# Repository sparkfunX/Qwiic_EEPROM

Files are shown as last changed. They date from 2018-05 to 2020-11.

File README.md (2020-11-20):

Qwiic EEPROM - 512Kbit
=======================================

Qwiic EEPROM

[*Qwiic EEPROM - 512Kbit (SPX-14764)*](https://www.sparkfun.com/products/14764)

A simple breakout for the 512kbit common I2C EEPROMs.

Repository Contents
-------------------

* **/Hardware** - Eagle design files (.brd, .sch)
* **/Firmware** - EEPROM test sketch

Documentation
------------

* **[SparkFun External EEPROM Arduino Library](https://github.com/sparkfun/SparkFun_External_EEPROM_Arduino_Library)** - Arduino library for the Qwiic EEPROM - 512Kbit
* **[Datasheet CAT24C512](https://www.onsemi.com/pub/Collateral/CAT24C512-D.PDF)** - Datasheet for EEPROM part number 24512A
* **[Datasheet RM24C512C](https://cdn.sparkfun.com/assets/2/c/4/c/0/DS-RM24C512C_082.pdf)** - Datasheet for EEPROM part number 24512C
* **[Reading and Writing Serial EEPROMs](https://learn.sparkfun.com/tutorials/reading-and-writing-serial-eeproms)** - Tutorial  

License Information
-------------------

This product is _**open source**_! 

Please review the LICENSE.md file for license information. 

If you have any questions or concerns on licensing, please contact technical support on our [SparkFun forums](https://forum.sparkfun.com/viewforum.php?f=152).

Distributed as-is; no warranty is given.

- Your friends at SparkFun.

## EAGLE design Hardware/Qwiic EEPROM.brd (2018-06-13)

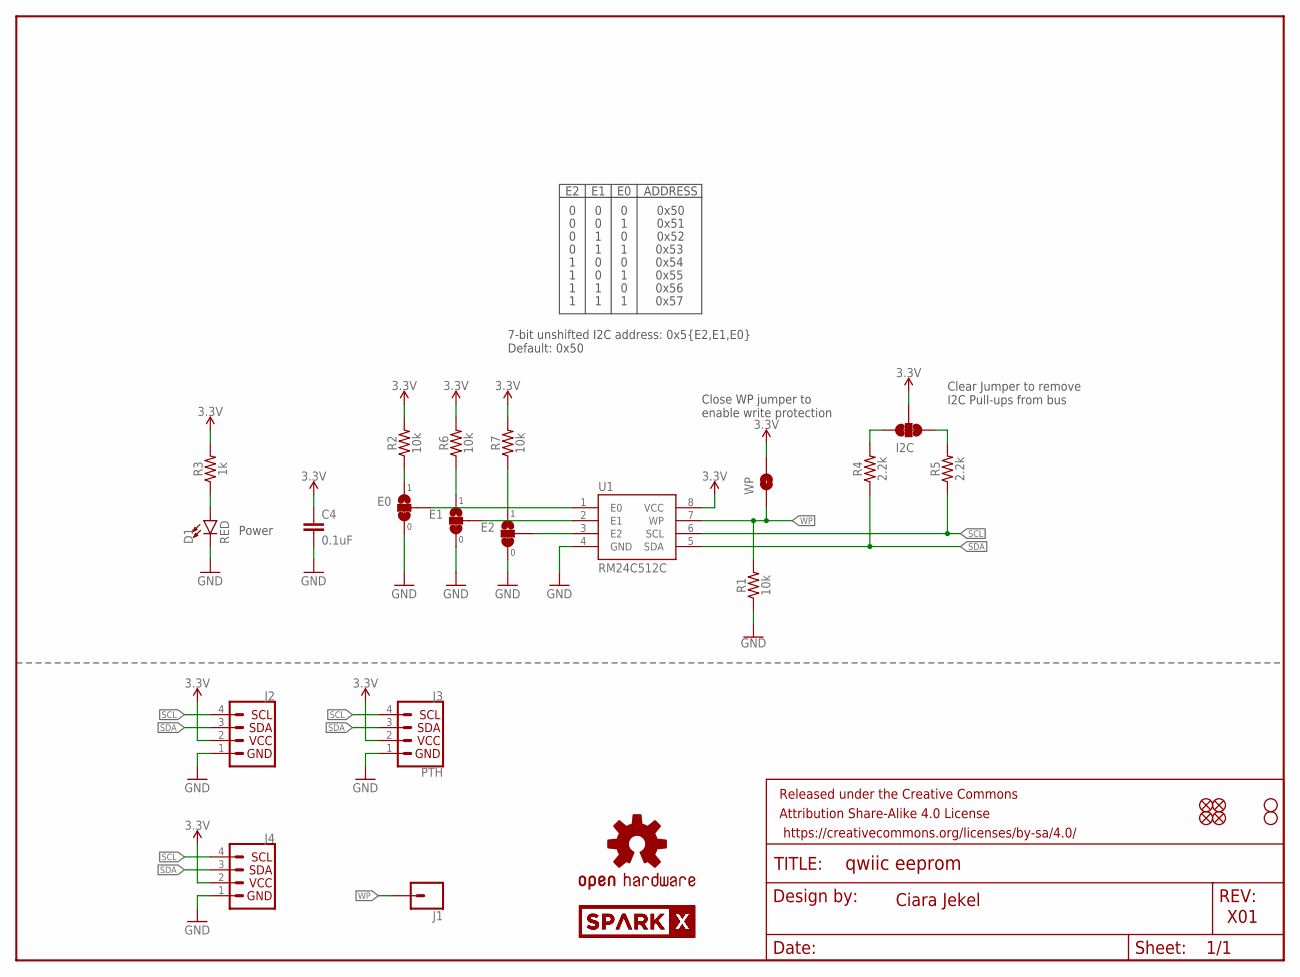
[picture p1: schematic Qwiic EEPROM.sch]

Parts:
C4: 0.1uF; 0603
D1: RED; LED-0603
E0, E1, E2: JUMPER-SMT_3_1-NC_TRACE_SILK; SMT-JUMPER_3_1-NC_TRACE_SILK
FRAME1: FRAME-LETTER; CREATIVE_COMMONS
I2C: JUMPER-SMT_3_2-NC_TRACE_SILK; SMT-JUMPER_3_2-NC_TRACE_SILK
J1: CONN_01PTH_NO_SILK_YES_STOP; 1X01_NO_SILK
J2, J4: QWIIC_CONNECTORJS-1MM; 1X04_1MM_RA
J3: PTH; 1X04_NO_SILK
JP1, JP2, JP5, JP6: FIDUCIALUFIDUCIAL; MICRO-FIDUCIAL
JP3, JP4: STAND-OFF
LOGO1: OSHW-LOGOMINI; OSHW-LOGO-MINI
R1, R2, R6, R7: 10k; 0603
R3: 1k; 0603
R4, R5: 2.2k; 0603
U1: RM24C512C; SO08
U$1, U$2: SPARKX-LOGO4; SPARKX-MEDIUM
WP: JUMPER-SMT_2_NO_SILK; SMT-JUMPER_2_NO_SILK

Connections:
3.3V: C4.1, I2C.2, J2.2, J3.2 (VCC), J4.2, R2.2, R3.2, R6.2, R7.2, U1.8 (VCC), WP.2
GND: C4.2, D1.C, E0.3, E1.3, E2.3, J2.1, J3.1 (GND), J4.1, R1.1, U1.4 (GND)
unnamed: I2C.1, R5.2
unnamed: I2C.3, R4.2
unnamed: D1.A, R3.1
unnamed: E2.2, U1.3 (E2)
unnamed: E1.2, U1.2 (E1)
unnamed: E0.2, U1.1 (E0)
unnamed: E0.1, R2.1
unnamed: E2.1, R7.1
unnamed: E1.1, R6.1
SCL: J2.4, J3.4 (SCL), J4.4, R5.1, U1.6 (SCL)
SDA: J2.3, J3.3 (SDA), J4.3, R4.1, U1.5 (SDA)
WP: J1.1, R1.2, U1.7 (WP), WP.1

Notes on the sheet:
Ciara Jekel
X01
7-bit unshifted I2C address: 0x5{E2,E1,E0} Default: 0x50
Clear Jumper to remove I2C Pull-ups from bus
Power
Close WP jumper to enable write protection
ADDRESS
0x50
0x51
0x52
0x53
0x54
0x55
0x56
0x57

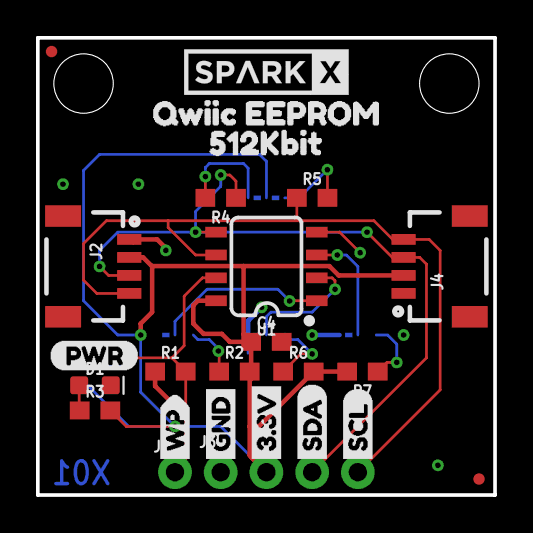
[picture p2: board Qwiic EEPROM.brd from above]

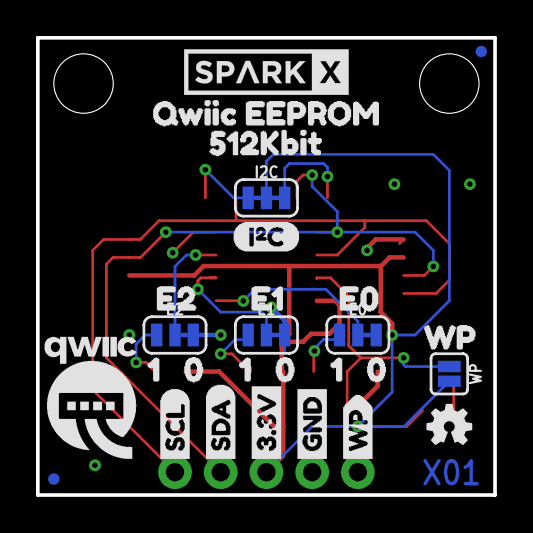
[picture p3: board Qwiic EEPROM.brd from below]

Board: 2 copper layers, 25.4 x 25.4 mm, 56 parts (28 on the bottom side), 14 nets.

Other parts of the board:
U$3, U$22: GND1
U$4, U$21: 3#3V2
U$5, U$27: SDA8
U$6, U$26: SCL9
U$7: WP6
U$8: E05
U$9: E23
U$10: (PWR)
U$11: (I_SUPER2_C)
U$12, U$18, U$19: 00
U$13: E14
U$14, U$17: 512KBIT7
U$15, U$16: QWIIC_EEPROM2
U$20, U$23, U$24: 11
U$25, U$28: WP2
U$29: QWIIC-LOGO-MEDIUM

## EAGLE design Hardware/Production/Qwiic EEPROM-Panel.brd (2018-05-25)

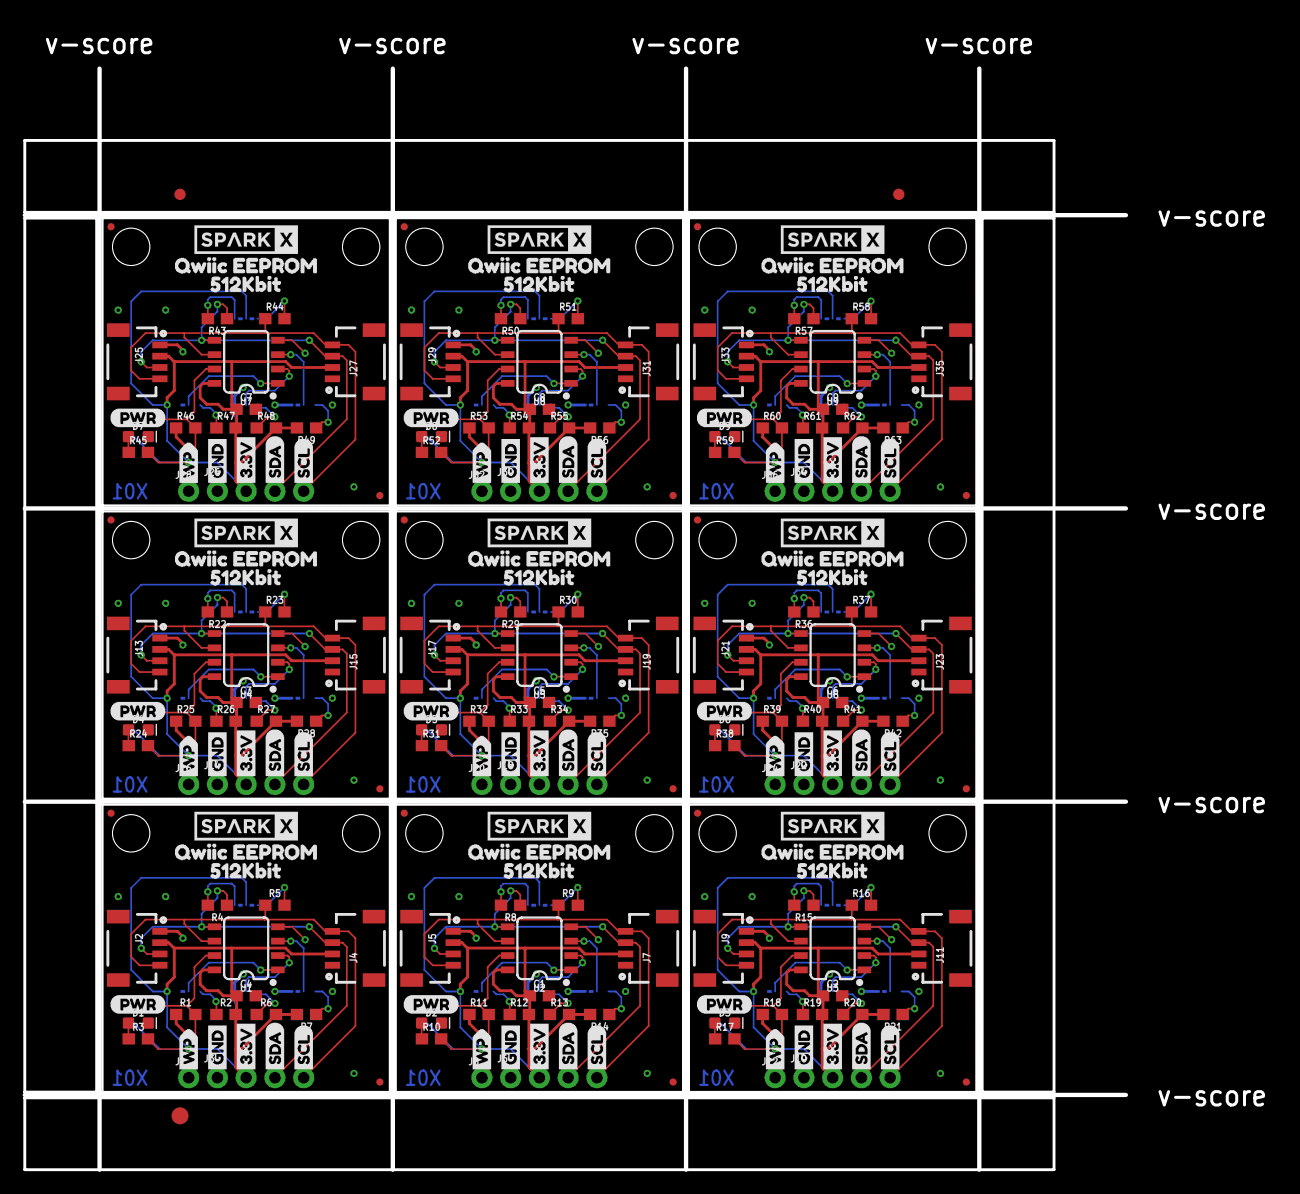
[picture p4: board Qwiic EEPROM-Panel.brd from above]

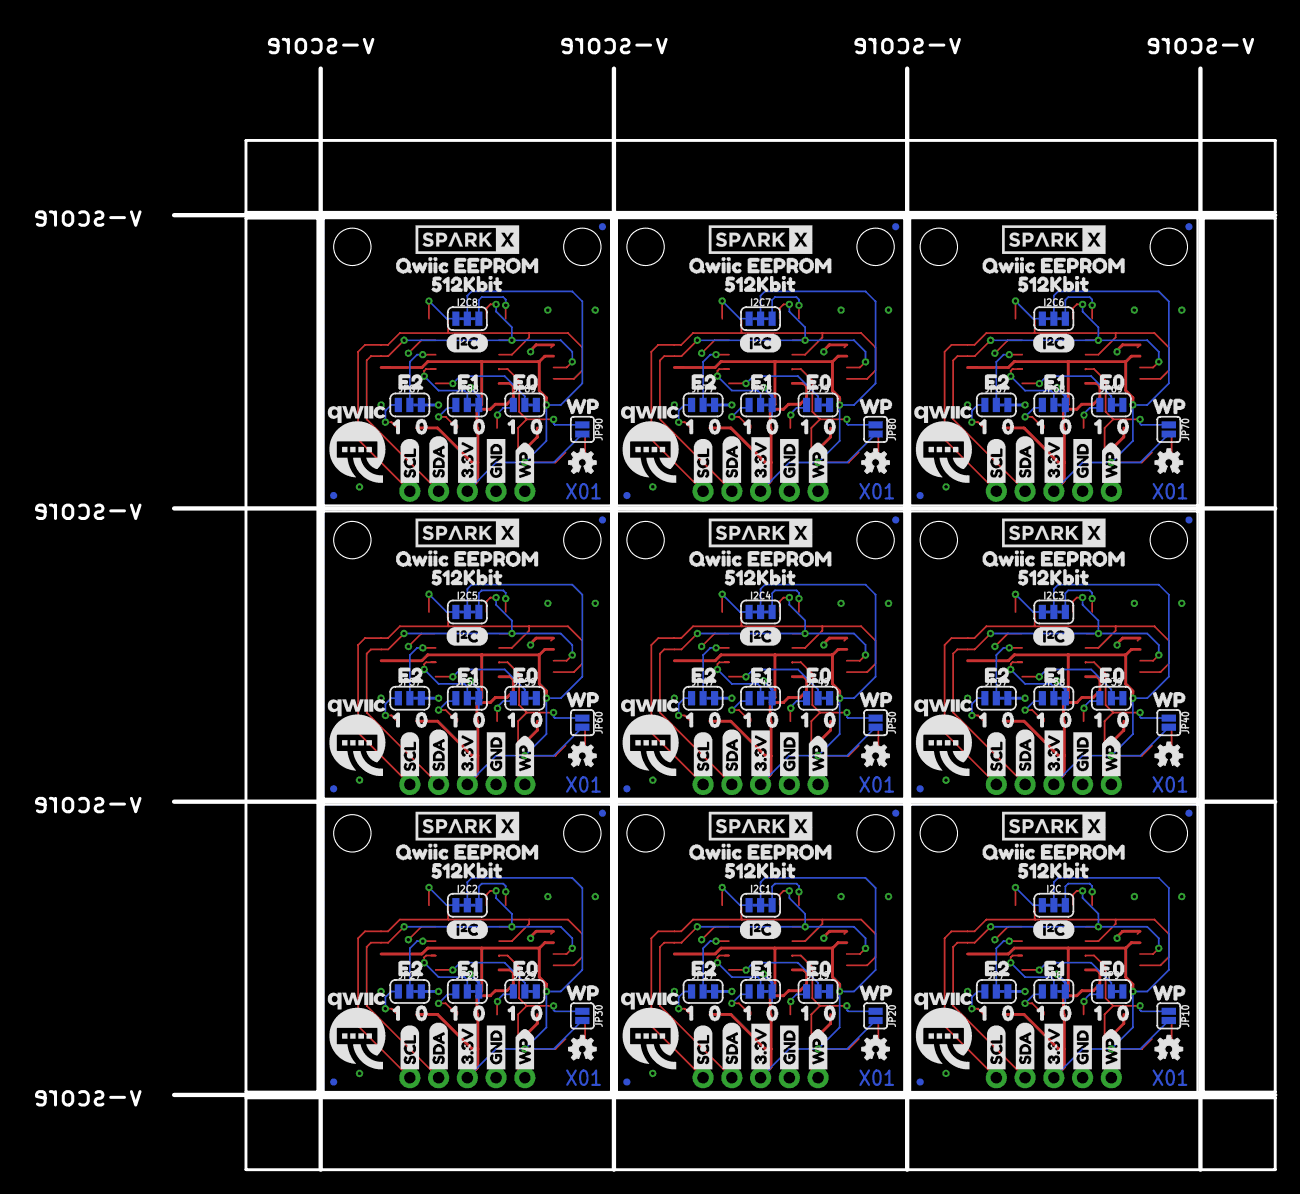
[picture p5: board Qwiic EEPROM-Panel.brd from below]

Board: 2 copper layers, 97.3 x 97.3 mm, 498 parts (252 on the bottom side), 126 nets.

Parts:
C1, C2, C3, C4, C5, C6, C7, C8, C9: 0.1uF; 0603
D1, D2, D3, D4, D5, D6, D7, D8, D9: RED; LED-0603
E$1, E$2: FIDUCIAL-1X2
E$3: FIDUCIAL-1.5X3
I2C, I2C1, I2C2, I2C3, I2C4, I2C5, I2C6, I2C7, I2C8: SMT-JUMPER_3_2-NC_TRACE_SILK
J1, J8, J12, J16, J20, J24, J28, J32, J36: 1X01_NO_SILK
J2, J4, J5, J7, J9, J11, J13, J15, J17, J19, J21, J23, J25, J27, J29, J31, J33, J35: SMD; 1X04_1MM_RA
J3, J6, J10, J14, J18, J22, J26, J30, J34: PTH; 1X04_NO_SILK
JP1, JP2, JP5, JP6, JP13, JP14, JP15, JP16, JP23, JP24, JP25, JP26, JP33, JP34, JP35, JP36, JP43, JP44, JP45, JP46, JP53, JP54, JP55, JP56, JP63, JP64, JP65, JP66, JP73, JP74, JP75, JP76, JP83, JP84, JP85, JP86: FIDUCIALUFIDUCIAL; MICRO-FIDUCIAL
JP3, JP4, JP11, JP12, JP21, JP22, JP31, JP32, JP41, JP42, JP51, JP52, JP61, JP62, JP71, JP72, JP81, JP82: STAND-OFF
JP7, JP8, JP9, JP17, JP18, JP19, JP27, JP28, JP29, JP37, JP38, JP39, JP47, JP48, JP49, JP57, JP58, JP59, JP67, JP68, JP69, JP77, JP78, JP79, JP87, JP88, JP89: SMT-JUMPER_3_1-NC_TRACE_SILK
JP10, JP20, JP30, JP40, JP50, JP60, JP70, JP80, JP90: SMT-JUMPER_2_NO_SILK
LOGO1, LOGO2, LOGO3, LOGO4, LOGO5, LOGO6, LOGO7, LOGO8, LOGO9: OSHW-LOGOMINI; OSHW-LOGO-MINI
R1, R2, R6, R7, R11, R12, R13, R14, R18, R19, R20, R21, R25, R26, R27, R28, R32, R33, R34, R35, R39, R40, R41, R42, R46, R47, R48, R49, R53, R54, R55, R56, R60, R61, R62, R63: 10k; 0603
R3, R10, R17, R24, R31, R38, R45, R52, R59: 1k; 0603
R4, R5, R8, R9, R15, R16, R22, R23, R29, R30, R36, R37, R43, R44, R50, R51, R57, R58: 2.2k; 0603
U1, U2, U3, U4, U5, U6, U7, U8, U9: RM24C5; SO08
U$1, U$2, U$30, U$31, U$59, U$60, U$88, U$89, U$117, U$118, U$146, U$147, U$175, U$176, U$204, U$205, U$233, U$234: SPARKX-LOGO4; SPARKX-MEDIUM
U$3, U$22, U$33, U$36, U$62, U$65, U$91, U$94, U$120, U$123, U$149, U$152, U$178, U$181, U$207, U$210, U$236, U$239: GND1
U$4, U$21, U$32, U$37, U$61, U$66, U$90, U$95, U$119, U$124, U$148, U$153, U$177, U$182, U$206, U$211, U$235, U$240: 3#3V2
U$5, U$27, U$35, U$38, U$64, U$67, U$93, U$96, U$122, U$125, U$151, U$154, U$180, U$183, U$209, U$212, U$238, U$241: SDA8
U$6, U$26, U$34, U$39, U$63, U$68, U$92, U$97, U$121, U$126, U$150, U$155, U$179, U$184, U$208, U$213, U$237, U$242: SCL9
U$7, U$42, U$71, U$100, U$129, U$158, U$187, U$216, U$245: WP6
U$8, U$43, U$72, U$101, U$130, U$159, U$188, U$217, U$246: E05
U$9, U$44, U$73, U$102, U$131, U$160, U$189, U$218, U$247: E23
U$10, U$40, U$69, U$98, U$127, U$156, U$185, U$214, U$243: (PWR)
U$11, U$41, U$70, U$99, U$128, U$157, U$186, U$215, U$244: (I_SUPER2_C)
U$12, U$18, U$19, U$50, U$51, U$52, U$79, U$80, U$81, U$108, U$109, U$110, U$137, U$138, U$139, U$166, U$167, U$168, U$195, U$196, U$197, U$224, U$225, U$226, U$253, U$254, U$255: 00
U$13, U$45, U$74, U$103, U$132, U$161, U$190, U$219, U$248: E14
U$14, U$17, U$46, U$49, U$75, U$78, U$104, U$107, U$133, U$136, U$162, U$165, U$191, U$194, U$220, U$223, U$249, U$252: 512KBIT7
U$15, U$16, U$47, U$48, U$76, U$77, U$105, U$106, U$134, U$135, U$163, U$164, U$192, U$193, U$221, U$222, U$250, U$251: QWIIC_EEPROM2
U$20, U$23, U$24, U$53, U$54, U$55, U$82, U$83, U$84, U$111, U$112, U$113, U$140, U$141, U$142, U$169, U$170, U$171, U$198, U$199, U$200, U$227, U$228, U$229, U$256, U$257, U$258: 11
U$25, U$28, U$56, U$57, U$85, U$86, U$114, U$115, U$143, U$144, U$172, U$173, U$201, U$202, U$230, U$231, U$259, U$260: WP2
U$29, U$58, U$87, U$116, U$145, U$174, U$203, U$232, U$261: QWIIC-LOGO-MEDIUM

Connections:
3.3V: C4.1, I2C.2, J2.2, J3.2, J4.2, JP10.2, R2.2, R3.2, R6.2, R7.2, U1.8
3.3V1: C1.1, I2C1.2, J5.2, J6.2, J7.2, JP20.2, R10.2, R12.2, R13.2, R14.2, U2.8
3.3V2: C2.1, I2C2.2, J9.2, J10.2, J11.2, JP30.2, R17.2, R19.2, R20.2, R21.2, U3.8
3.3V3: C3.1, I2C3.2, J13.2, J14.2, J15.2, JP40.2, R24.2, R26.2, R27.2, R28.2, U4.8
3.3V4: C5.1, I2C4.2, J17.2, J18.2, J19.2, JP50.2, R31.2, R33.2, R34.2, R35.2, U5.8
3.3V5: C6.1, I2C5.2, J21.2, J22.2, J23.2, JP60.2, R38.2, R40.2, R41.2, R42.2, U6.8
3.3V6: C7.1, I2C6.2, J25.2, J26.2, J27.2, JP70.2, R45.2, R47.2, R48.2, R49.2, U7.8
3.3V7: C8.1, I2C7.2, J29.2, J30.2, J31.2, JP80.2, R52.2, R54.2, R55.2, R56.2, U8.8
3.3V8: C9.1, I2C8.2, J33.2, J34.2, J35.2, JP90.2, R59.2, R61.2, R62.2, R63.2, U9.8
GND: C4.2, D1.C, J2.1, J3.1, J4.1, JP7.3, JP8.3, JP9.3, R1.1, U1.4
GND1: C1.2, D2.C, J5.1, J6.1, J7.1, JP17.3, JP18.3, JP19.3, R11.1, U2.4
GND2: C2.2, D3.C, J9.1, J10.1, J11.1, JP27.3, JP28.3, JP29.3, R18.1, U3.4
GND3: C3.2, D4.C, J13.1, J14.1, J15.1, JP37.3, JP38.3, JP39.3, R25.1, U4.4
GND4: C5.2, D5.C, J17.1, J18.1, J19.1, JP47.3, JP48.3, JP49.3, R32.1, U5.4
GND5: C6.2, D6.C, J21.1, J22.1, J23.1, JP57.3, JP58.3, JP59.3, R39.1, U6.4
GND6: C7.2, D7.C, J25.1, J26.1, J27.1, JP67.3, JP68.3, JP69.3, R46.1, U7.4
GND7: C8.2, D8.C, J29.1, J30.1, J31.1, JP77.3, JP78.3, JP79.3, R53.1, U8.4
GND8: C9.2, D9.C, J33.1, J34.1, J35.1, JP87.3, JP88.3, JP89.3, R60.1, U9.4
unnamed: I2C.1, R5.2
unnamed: I2C.3, R4.2
unnamed: D1.A, R3.1
unnamed: JP7.2, U1.3
unnamed: JP8.2, U1.2
unnamed: JP9.2, U1.1
unnamed: JP9.1, R2.1
unnamed: JP7.1, R7.1
unnamed: JP8.1, R6.1
unnamed: I2C1.1, R9.2
unnamed: I2C1.3, R8.2
unnamed: D2.A, R10.1
unnamed: JP17.2, U2.3
unnamed: JP18.2, U2.2
unnamed: JP19.2, U2.1
unnamed: JP19.1, R12.1
unnamed: JP17.1, R14.1
unnamed: JP18.1, R13.1
unnamed: I2C2.1, R16.2
unnamed: I2C2.3, R15.2
unnamed: D3.A, R17.1
unnamed: JP27.2, U3.3
unnamed: JP28.2, U3.2
unnamed: JP29.2, U3.1
unnamed: JP29.1, R19.1
unnamed: JP27.1, R21.1
unnamed: JP28.1, R20.1
unnamed: I2C3.1, R23.2
unnamed: I2C3.3, R22.2
unnamed: D4.A, R24.1
unnamed: JP37.2, U4.3
unnamed: JP38.2, U4.2
unnamed: JP39.2, U4.1
unnamed: JP39.1, R26.1
unnamed: JP37.1, R28.1
unnamed: JP38.1, R27.1
unnamed: I2C4.1, R30.2
unnamed: I2C4.3, R29.2
unnamed: D5.A, R31.1
unnamed: JP47.2, U5.3
unnamed: JP48.2, U5.2
unnamed: JP49.2, U5.1
unnamed: JP49.1, R33.1
unnamed: JP47.1, R35.1
unnamed: JP48.1, R34.1
unnamed: I2C5.1, R37.2
unnamed: I2C5.3, R36.2
unnamed: D6.A, R38.1
unnamed: JP57.2, U6.3
unnamed: JP58.2, U6.2
unnamed: JP59.2, U6.1
unnamed: JP59.1, R40.1
unnamed: JP57.1, R42.1
unnamed: JP58.1, R41.1
unnamed: I2C6.1, R44.2
unnamed: I2C6.3, R43.2
unnamed: D7.A, R45.1
unnamed: JP67.2, U7.3
unnamed: JP68.2, U7.2
unnamed: JP69.2, U7.1
unnamed: JP69.1, R47.1
unnamed: JP67.1, R49.1
unnamed: JP68.1, R48.1
unnamed: I2C7.1, R51.2
unnamed: I2C7.3, R50.2
unnamed: D8.A, R52.1
unnamed: JP77.2, U8.3
unnamed: JP78.2, U8.2
unnamed: JP79.2, U8.1
unnamed: JP79.1, R54.1
unnamed: JP77.1, R56.1
unnamed: JP78.1, R55.1
unnamed: I2C8.1, R58.2
unnamed: I2C8.3, R57.2
unnamed: D9.A, R59.1
unnamed: JP87.2, U9.3
unnamed: JP88.2, U9.2
unnamed: JP89.2, U9.1
unnamed: JP89.1, R61.1
unnamed: JP87.1, R63.1
unnamed: JP88.1, R62.1
SCL: J2.4, J3.4, J4.4, R5.1, U1.6
SCL1: J5.4, J6.4, J7.4, R9.1, U2.6
SCL2: J9.4, J10.4, J11.4, R16.1, U3.6
SCL3: J13.4, J14.4, J15.4, R23.1, U4.6
SCL4: J17.4, J18.4, J19.4, R30.1, U5.6
SCL5: J21.4, J22.4, J23.4, R37.1, U6.6
SCL6: J25.4, J26.4, J27.4, R44.1, U7.6
SCL7: J29.4, J30.4, J31.4, R51.1, U8.6
SCL8: J33.4, J34.4, J35.4, R58.1, U9.6
SDA: J2.3, J3.3, J4.3, R4.1, U1.5
SDA1: J5.3, J6.3, J7.3, R8.1, U2.5
SDA2: J9.3, J10.3, J11.3, R15.1, U3.5
SDA3: J13.3, J14.3, J15.3, R22.1, U4.5
SDA4: J17.3, J18.3, J19.3, R29.1, U5.5
SDA5: J21.3, J22.3, J23.3, R36.1, U6.5
SDA6: J25.3, J26.3, J27.3, R43.1, U7.5
SDA7: J29.3, J30.3, J31.3, R50.1, U8.5
SDA8: J33.3, J34.3, J35.3, R57.1, U9.5
WP: J1.1, JP10.1, R1.2, U1.7
WP1: J8.1, JP20.1, R11.2, U2.7
WP2: J12.1, JP30.1, R18.2, U3.7
WP3: J16.1, JP40.1, R25.2, U4.7
WP4: J20.1, JP50.1, R32.2, U5.7
WP5: J24.1, JP60.1, R39.2, U6.7
WP6: J28.1, JP70.1, R46.2, U7.7
WP7: J32.1, JP80.1, R53.2, U8.7
WP8: J36.1, JP90.1, R60.2, U9.7

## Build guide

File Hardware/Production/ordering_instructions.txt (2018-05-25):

panel size, 91x91mm
PCB thickness, 1.6mm
number of layers, 2
soldermask color, Black
silkscreen color, White
oz copper, 1oz
finish, HASL lead free
stencils, top
pcs per panel, 9

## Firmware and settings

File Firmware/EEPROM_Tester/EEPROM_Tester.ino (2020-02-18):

/*
  A simple test for our Qwiic EEPROM board.
*/

#include <Wire.h>

#include "SparkFun_External_EEPROM.h" // Click here to get the library: http://librarymanager/All#SparkFun_External_EEPROM
ExternalEEPROM myMem;

const int LED = 13;

void setup()
{
  Serial.begin(115200);
  Serial.println("Qwiic EEPROM Tester");

  pinMode(LED, OUTPUT);

  Wire.begin();
}

void loop()
{
  if (myMem.begin() == true)
  {
    Serial.println("EEPROM Detected");
    digitalWrite(LED, HIGH);
  }
  else
  {
    Serial.println("Nothing detected!");
    digitalWrite(LED, LOW);
  }
  delay(100);

}

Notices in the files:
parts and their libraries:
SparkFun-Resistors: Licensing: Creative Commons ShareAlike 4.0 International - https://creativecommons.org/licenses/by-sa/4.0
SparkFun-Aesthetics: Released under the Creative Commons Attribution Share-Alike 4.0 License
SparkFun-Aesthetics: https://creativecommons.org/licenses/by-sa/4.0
